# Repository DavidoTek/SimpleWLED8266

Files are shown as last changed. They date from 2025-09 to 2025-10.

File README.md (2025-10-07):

# SimpleWLED8266

SimpleWLED8266 is a simple, ESP8266-based, and WLED-powered LED controller board, supporting both analog and digital LED strips. The board features AO3400 mosfets to drive the analog LEDs and uses the 74AHCT125 buffer as a level-shifter for the digital LEDs which require 5V.

The board is very simple to solder since it only features a few parts and the smallest SMD part is of the size 0805. It does not use a switching regulator, reducing complexity and noise, but also decreasing the efficiency of the board. Make sure to pick 1117 regulators that support input voltages >12V! (e.g., LM1117 by TI)

The recommended software is [WLED](https://github.com/WLED/WLED), but other software like [ESPHome](https://esphome.io/) or [Tasmota](https://github.com/arendst/Tasmota) can also be used. Check out [this page](https://kno.wled.ge/basics/compatible-led-strips/) for a list of LED strips supported by WLED.

Disclaimer: This was made as a hobby project, so errors in the design are possible. Handle high voltages with care and do not overload the PCB since it can overheat and cause a fire. Please report problems in the design!

## Content

File/Folder                       | Description
----------------------------------|-------------------------------
simplewled8266/                   | KiCad project for the PCB
SimpleWLED8266_Case_Bottom.stl    | 3D-printable case (bottom)
SimpleWLED8266_Case_Bottom_ScrewMount.stl    | 3D-printable case (bottom, with screw mounts)
SimpleWLED8266_Case_Top.stl       | 3D-printable case (top)
SimpleWLED8266_Label.pdf          | Label for the 3D-printed case

## Wiring

The following GPIO functions need to be configured in WLED:

GPIO        | Function
------------|----------------------
12          | Red (analog)
5           | Green (analog)
14          | Blue (analog)
2           | Data (digital)
13          | Clock (digital)
0           | Button

## BOM

Quantity | Type       | Value       | Description
---------|------------|-------------|-------------------------------------
7        | Capacitor  | 100n        | Decoupling capacitors
1        | Capacitor  | 10u         | Capacitor
1        | Capacitor  | 470u        | Capacitor
1        | Fuse       | Fuse        | Fuse
1        | Connector  | PWR         | 
1        | Connector  | LEDs        | 
1        | Connector  | PROG        | 
3        | MOSFET     | AO3400A     | N-channel MOSFET for analog LEDs
2        | Resistor   | 62          | Between level-shifter and LEDs
8        | Resistor   | 10k         | Pull-up / pull-down resistors
1        | Switch     | SW_Push     | 
1        | Module     | ESP-12F     | ESP8266
1        | Buffer     | 74AHCT125   | Buffer as level-shifter to 5V
1        | Regulator  | AMS1117-5.0 | 5V linear regulator, Vin>=12V
1        | Regulator  | AMS1117-3.3 | 3.3V linear regulator, Vin>=12V

## Photos

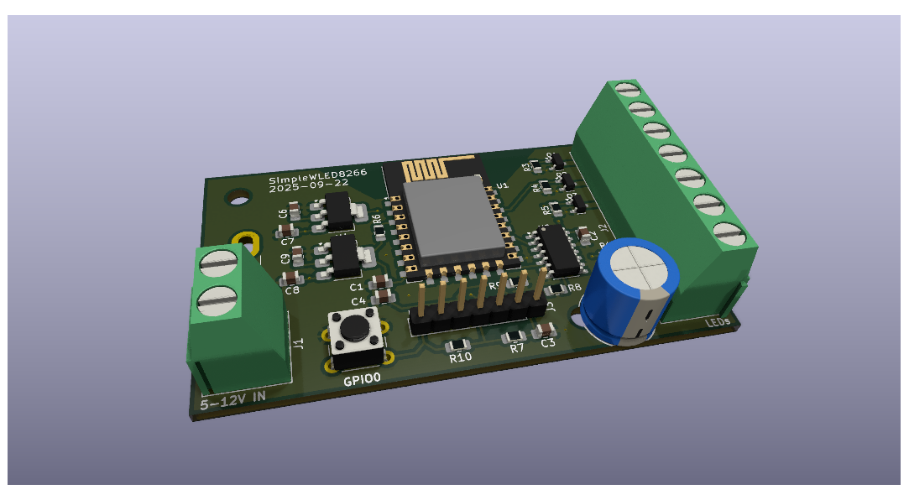
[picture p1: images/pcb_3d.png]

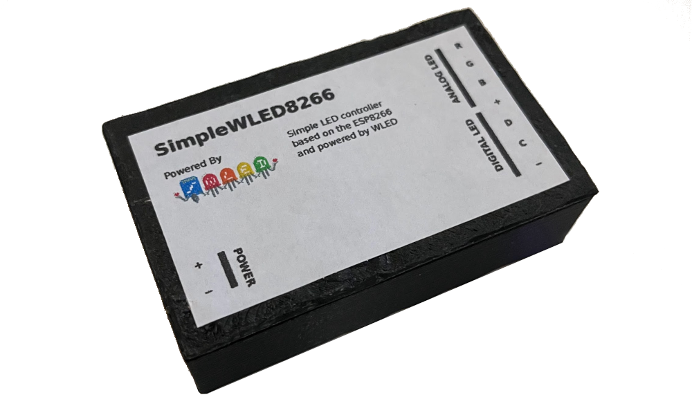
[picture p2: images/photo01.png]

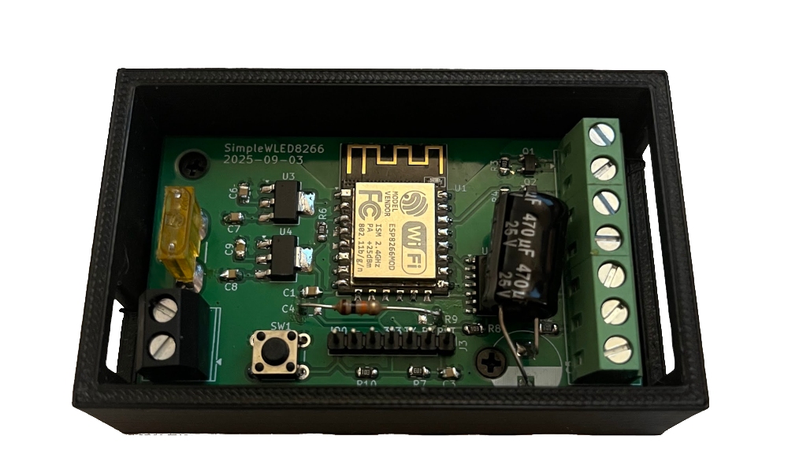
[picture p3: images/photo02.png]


Source of the WLED logo: https://github.com/wled/WLED/blob/main/images/wled_logo_akemi.png

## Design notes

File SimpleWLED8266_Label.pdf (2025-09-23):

# SimpleWLED8266

POWER ANALOG LED DIGITAL LED Powered By +

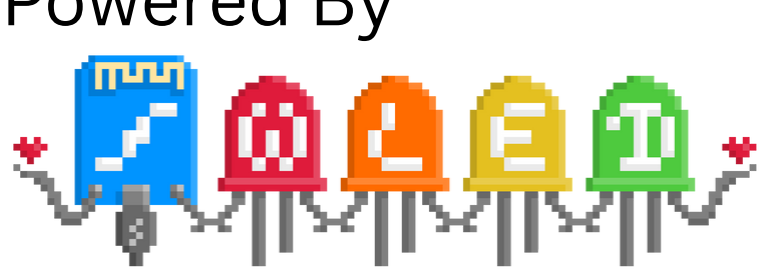
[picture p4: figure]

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
Simple LED controller
based on the ESP8266
and powered by WLED

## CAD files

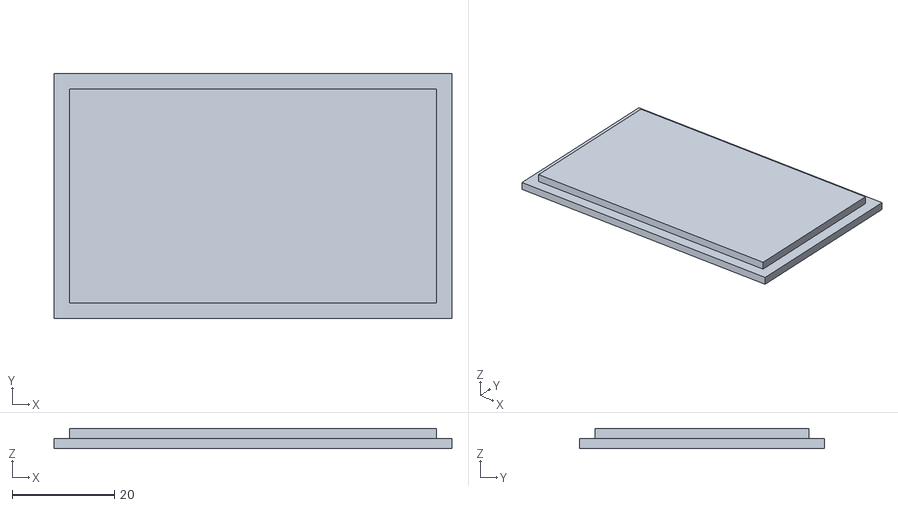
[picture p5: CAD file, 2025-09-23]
SimpleWLED8266_Case_Top.stl
78.0 x 48.0 x 4.00

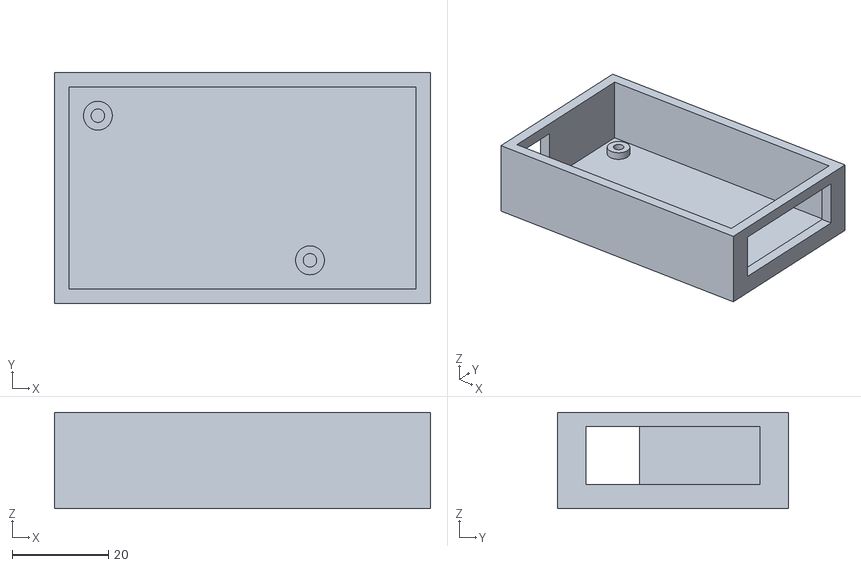
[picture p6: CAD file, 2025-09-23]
SimpleWLED8266_Case_Bottom.stl
78.0 x 48.0 x 20.0

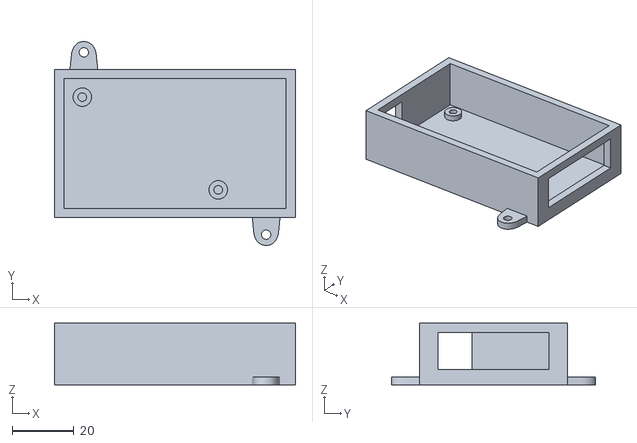
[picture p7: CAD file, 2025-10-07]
SimpleWLED8266_Case_Bottom_ScrewMount.stl
78.0 x 66.0 x 20.0

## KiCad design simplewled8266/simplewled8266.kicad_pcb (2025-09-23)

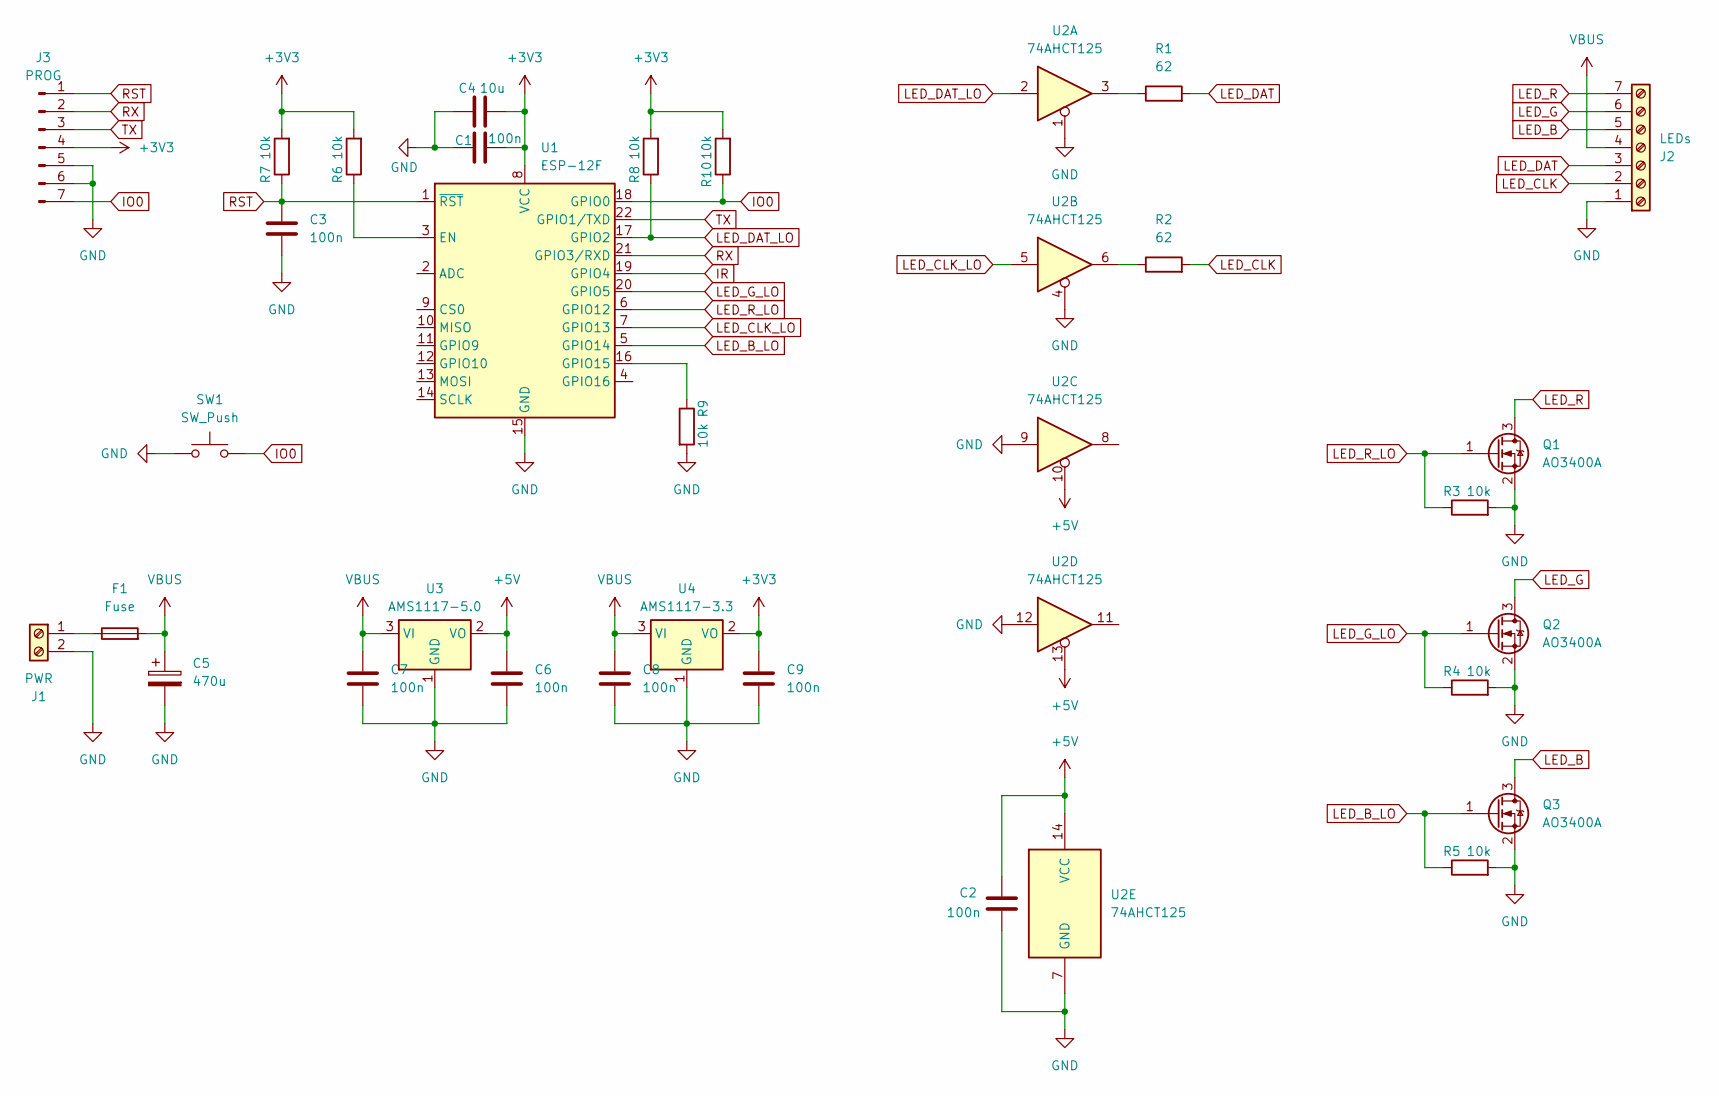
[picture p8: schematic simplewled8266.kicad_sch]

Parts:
C1, C2, C3, C6, C7, C8, C9: 100n; C_0805_2012Metric_Pad1.18x1.45mm_HandSolder
C4: 10u; C_0805_2012Metric_Pad1.18x1.45mm_HandSolder
C5: 470u; CP_Radial_D10.0mm_P5.00mm
F1: Fuse; Fuse_Blade_Mini_directSolder
J1: PWR; TerminalBlock_Phoenix_MKDS-1,5-2-5.08_1x02_P5.08mm_Horizont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
J2: LEDs; TerminalBlock_Phoenix_MKDS-1,5-7-5.08_1x07_P5.08mm_Horizont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
J3: PROG; PinHeader_1x07_P2.54mm_Vertical
Q1, Q2, Q3: AO3400A; SOT-23
R1, R2: 62; R_0805_2012Metric_Pad1.20x1.40mm_HandSolder
R3, R4, R5, R6, R7, R8, R9, R10: 10k; R_0805_2012Metric_Pad1.20x1.40mm_HandSolder
SW1: SW_Push; SW_PUSH_6mm
U1: ESP-12F; ESP-12E
U2: 74AHCT125; SOIC-14_3.9x8.7mm_P1.27mm
U3: AMS1117-5.0; SOT-223-3_TabPin2
U4: AMS1117-3.3; SOT-223-3_TabPin2

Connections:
+3V3: C1.2, C4.2, C9.1, J3.4, R6.2, R7.2, R8.2, R10.2, U1.8 (VCC), U4.2 (VO)
+5V: C2.1, C6.1, U2.10, U2.13, U2.14 (VCC), U3.2 (VO)
GND: C1.1, C2.2, C3.2, C4.1, C5.2, C6.2, C7.2, C8.2, C9.2, J1.2, J2.1, J3.5, J3.6, Q1.2 (S), Q2.2 (S), Q3.2 (S), R3.2, R4.2, R5.2, R9.2, SW1.1, U1.15 (GND), U2.1, U2.4, U2.7 (GND), U2.9, U2.12, U3.1 (GND), U4.1 (GND)
IO0: J3.7, R10.1, SW1.2, U1.18 (GPIO0)
IR: U1.19 (GPIO4)
LED_B: J2.5, Q3.3 (D)
LED_B_LO: Q3.1 (G), R5.1, U1.5 (GPIO14)
LED_CLK: J2.2, R2.2
LED_CLK_LO: U1.7 (GPIO13), U2.5
LED_DAT: J2.3, R1.2
LED_DAT_LO: R8.1, U1.17 (GPIO2), U2.2
LED_G: J2.6, Q2.3 (D)
LED_G_LO: Q2.1 (G), R4.1, U1.20 (GPIO5)
LED_R: J2.7, Q1.3 (D)
LED_R_LO: Q1.1 (G), R3.1, U1.6 (GPIO12)
unnamed: F1.1, J1.1
unnamed: R1.1, U2.3
unnamed: R2.1, U2.6
unnamed: R6.1, U1.3 (EN)
unnamed: R9.1, U1.16 (GPIO15)
RST: C3.1, J3.1, R7.1, U1.1 (~RST)
RX: J3.2, U1.21 (GPIO3/RXD)
TX: J3.3, U1.22 (GPIO1/TXD)
VBUS: C5.1, C7.1, C8.1, F1.2, J2.4, U3.3 (VI), U4.3 (VI)

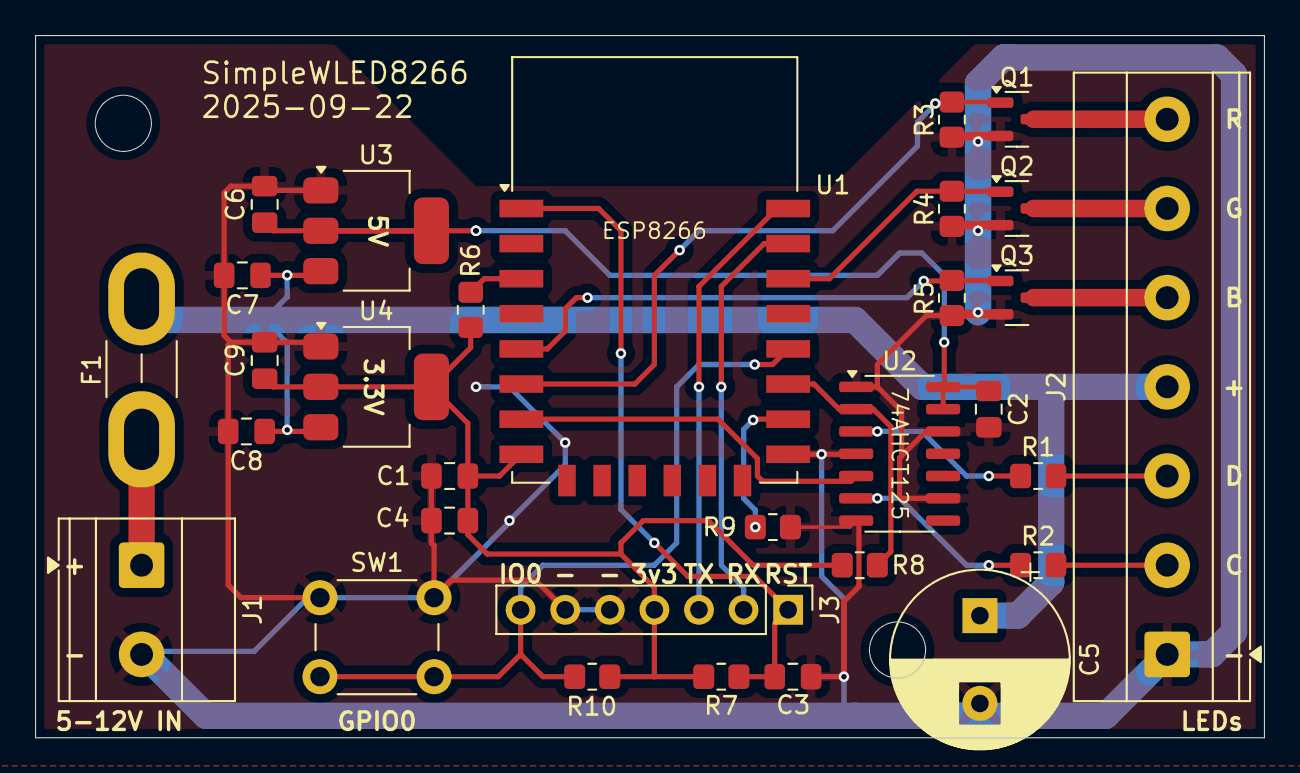
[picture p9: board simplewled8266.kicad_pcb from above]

Board: 2 copper layers, 70.0 x 40.0 mm, 31 parts (0 on the bottom side), 23 nets.
